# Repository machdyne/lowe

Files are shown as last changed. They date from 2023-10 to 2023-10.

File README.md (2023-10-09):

# Löwe FPGA Board

Löwe is an open-source FPGA development board for the Cologne Chip GateMate CCGM1A1.

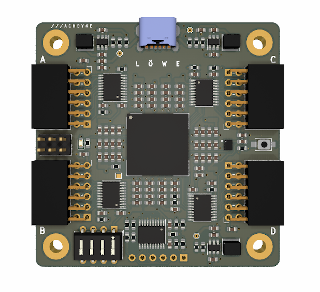
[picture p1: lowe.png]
Löwe FPGA Board


This repo contains PCB layouts, schematics, pinouts and example gateware.

Find more information on the [Löwe product page](https://machdyne.com/product/lowe-fpga-board/).

## Examples

In order to build the examples, first edit rtl/config.mk and set the paths to the location of your toolchain. You can download the toolchain from [Cologne Chip](https://colognechip.com).

You can build each example with:

```
$ make && make impl
```

You can then use [openFPGALoader](https://github.com/trabucayre/openFPGALoader) to write the gateware to SRAM or flash, using a Raspberry Pi Pico or [Werkzeug](https://github.com/machdyne/werkzeug) (loaded with [pico-dirtyJtag](https://github.com/phdussud/pico-dirtyJtag)) in this example:

```
$ openFPGALoader -c dirtyJtag count_00.cfg.bit
```

## Configuration Mode Selection

The board has 4 DIP switches that select the configuration mode:

| Switches | Mode |
| --- | --- |
| 0000 | SPI Active Mode (CPOL=0 CPHA=0) |
| 0001 | SPI Active Mode (CPOL=0 CPHA=1) |
| 0010 | SPI Active Mode (CPOL=1 CPHA=0) |
| 0011 | SPI Active Mode (CPOL=1 CPHA=1) |
| 0100 | SPI Passive Mode (CPOL=0 CPHA=0) |
| 0101 | SPI Passive Mode (CPOL=0 CPHA=1) |
| 0110 | SPI Passive Mode (CPOL=1 CPHA=0) |
| 0111 | SPI Passive Mode (CPOL=1 CPHA=1) |
| 1100 | JTAG |

## MMOD Header

See the [MMOD repo](https://github.com/machdyne/mmod/) for details.

## JTAG Header

The 3.3V JTAG header can be used to program the FPGA SRAM as well as the MMOD flash memory.

```
5 3 1
6 4 2
```

| Pin | Signal |
| --- | --- |
| 1 | TCK |
| 2 | TDI |
| 3 | TDO |
| 4 | TMS |
| 5 | 5V0[^1] |
| 6 | GND |

[^1]: This pin can be used to power the board with an external regulated 5V power supply, instead of USB power.

## Funding

This project was partially funded through the NGI0 Entrust Fund, a fund established by NLnet with financial support from the European Commission's Next Generation Internet programme.

## License

This project is released under the [CERN-OHL-P](LICENSE.txt) license.

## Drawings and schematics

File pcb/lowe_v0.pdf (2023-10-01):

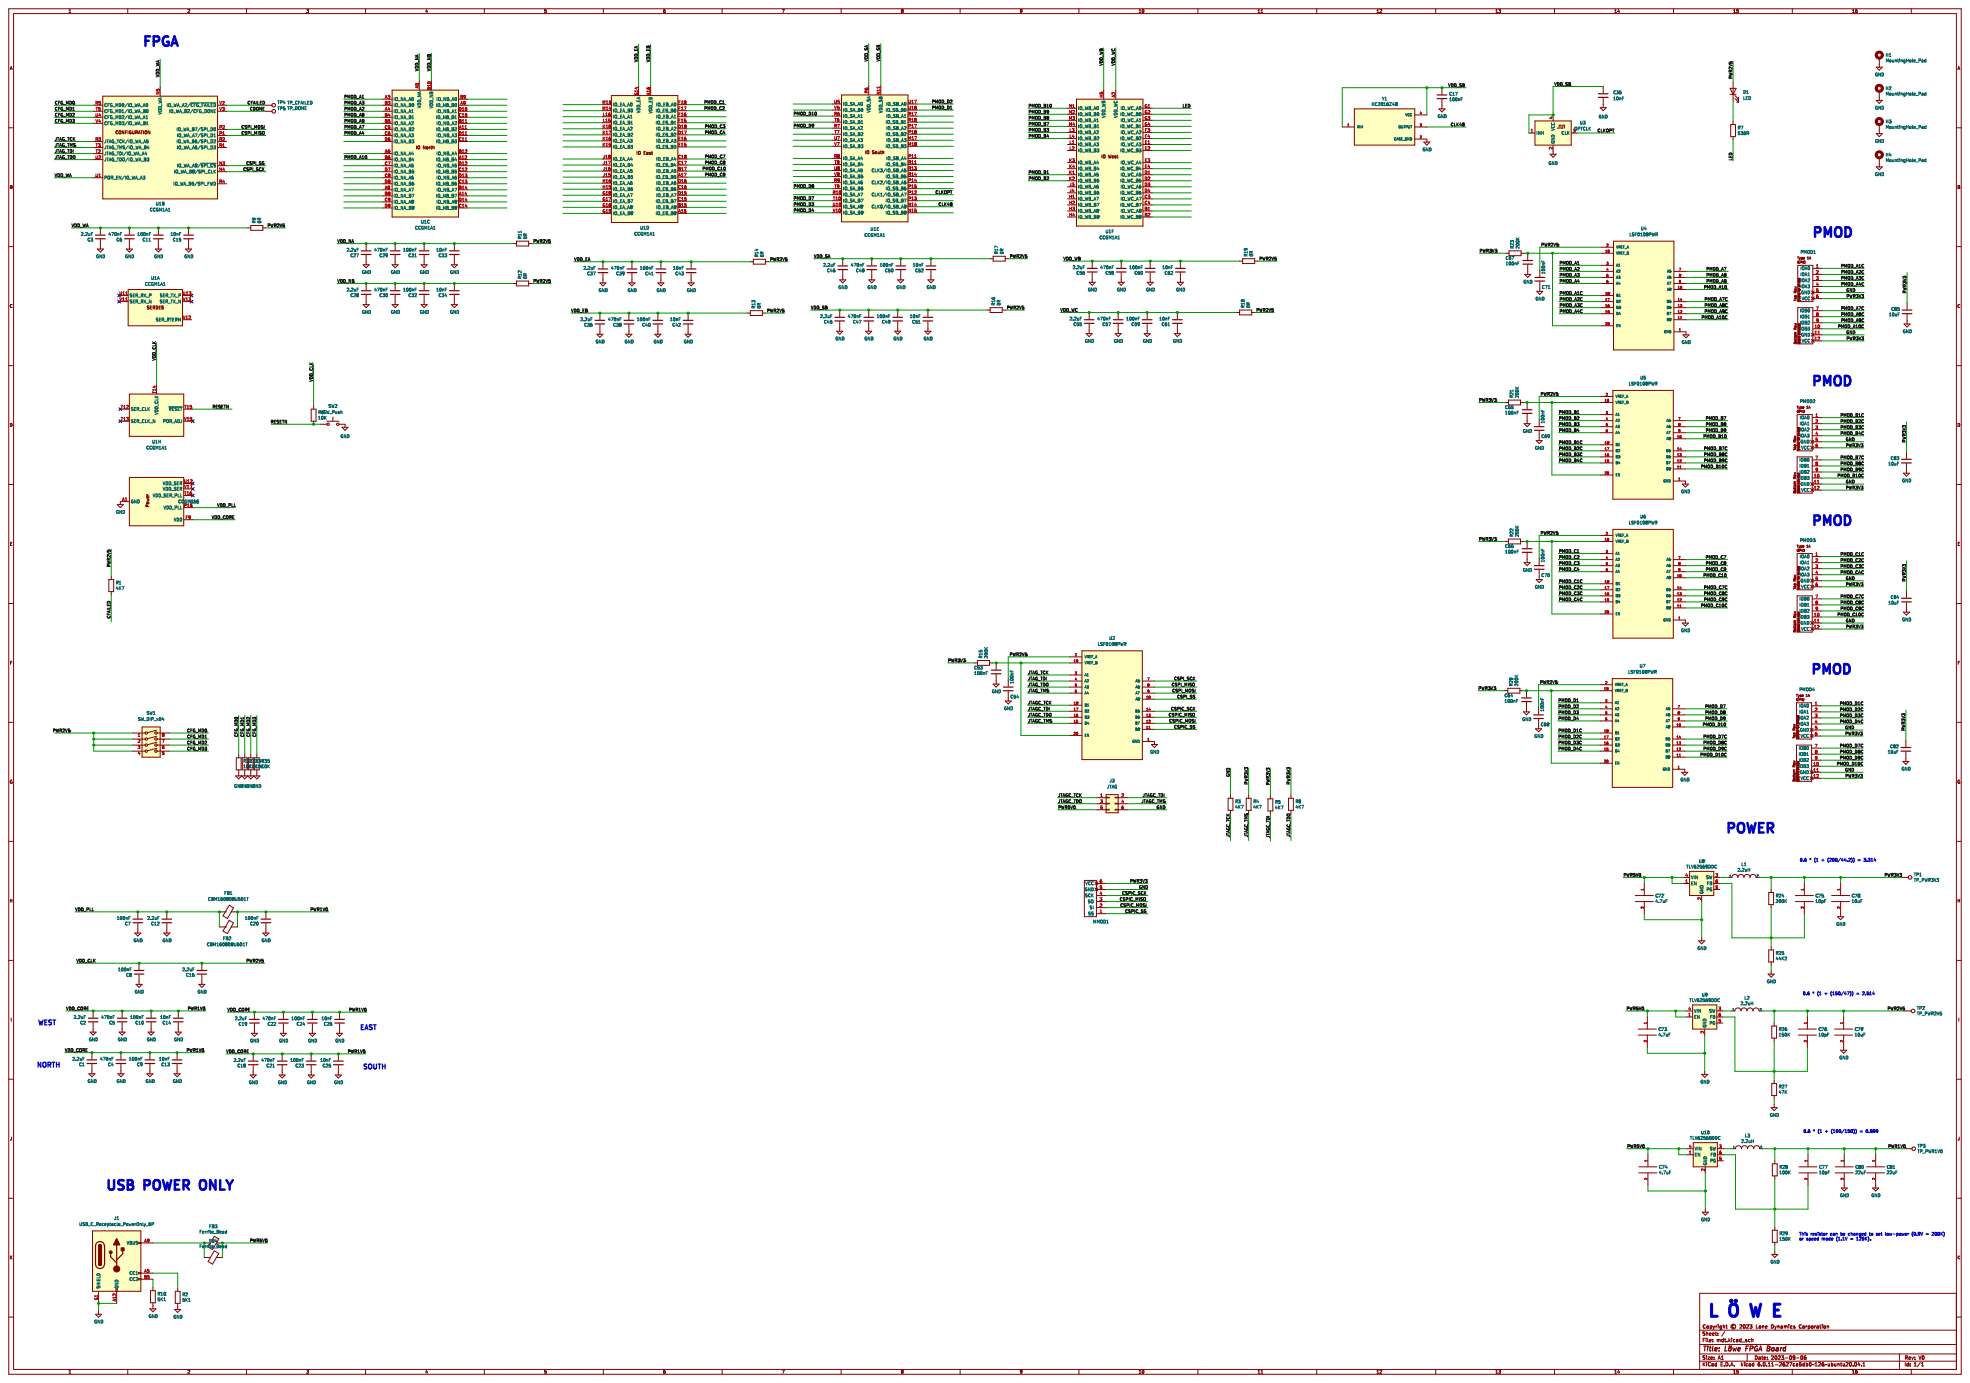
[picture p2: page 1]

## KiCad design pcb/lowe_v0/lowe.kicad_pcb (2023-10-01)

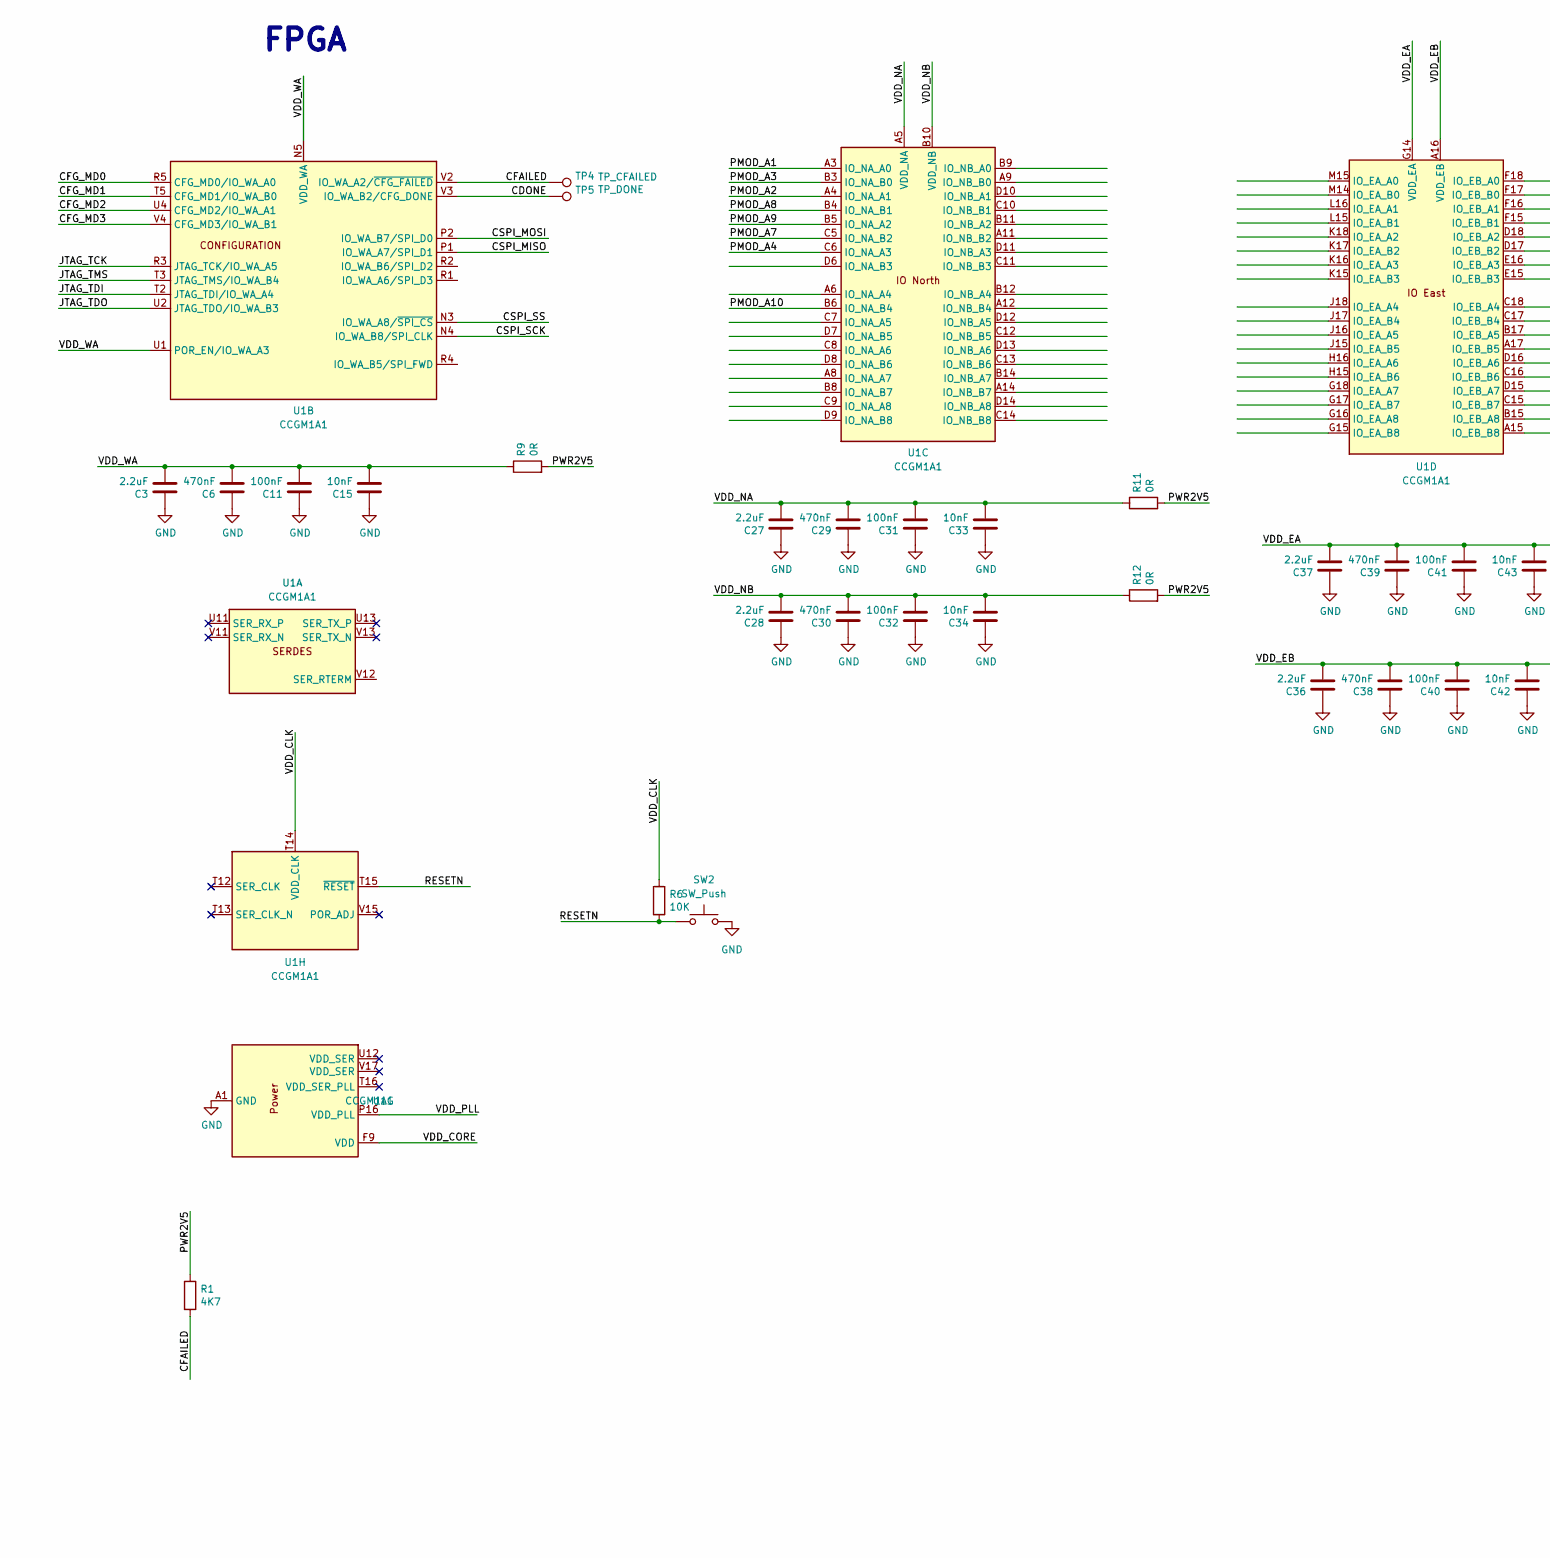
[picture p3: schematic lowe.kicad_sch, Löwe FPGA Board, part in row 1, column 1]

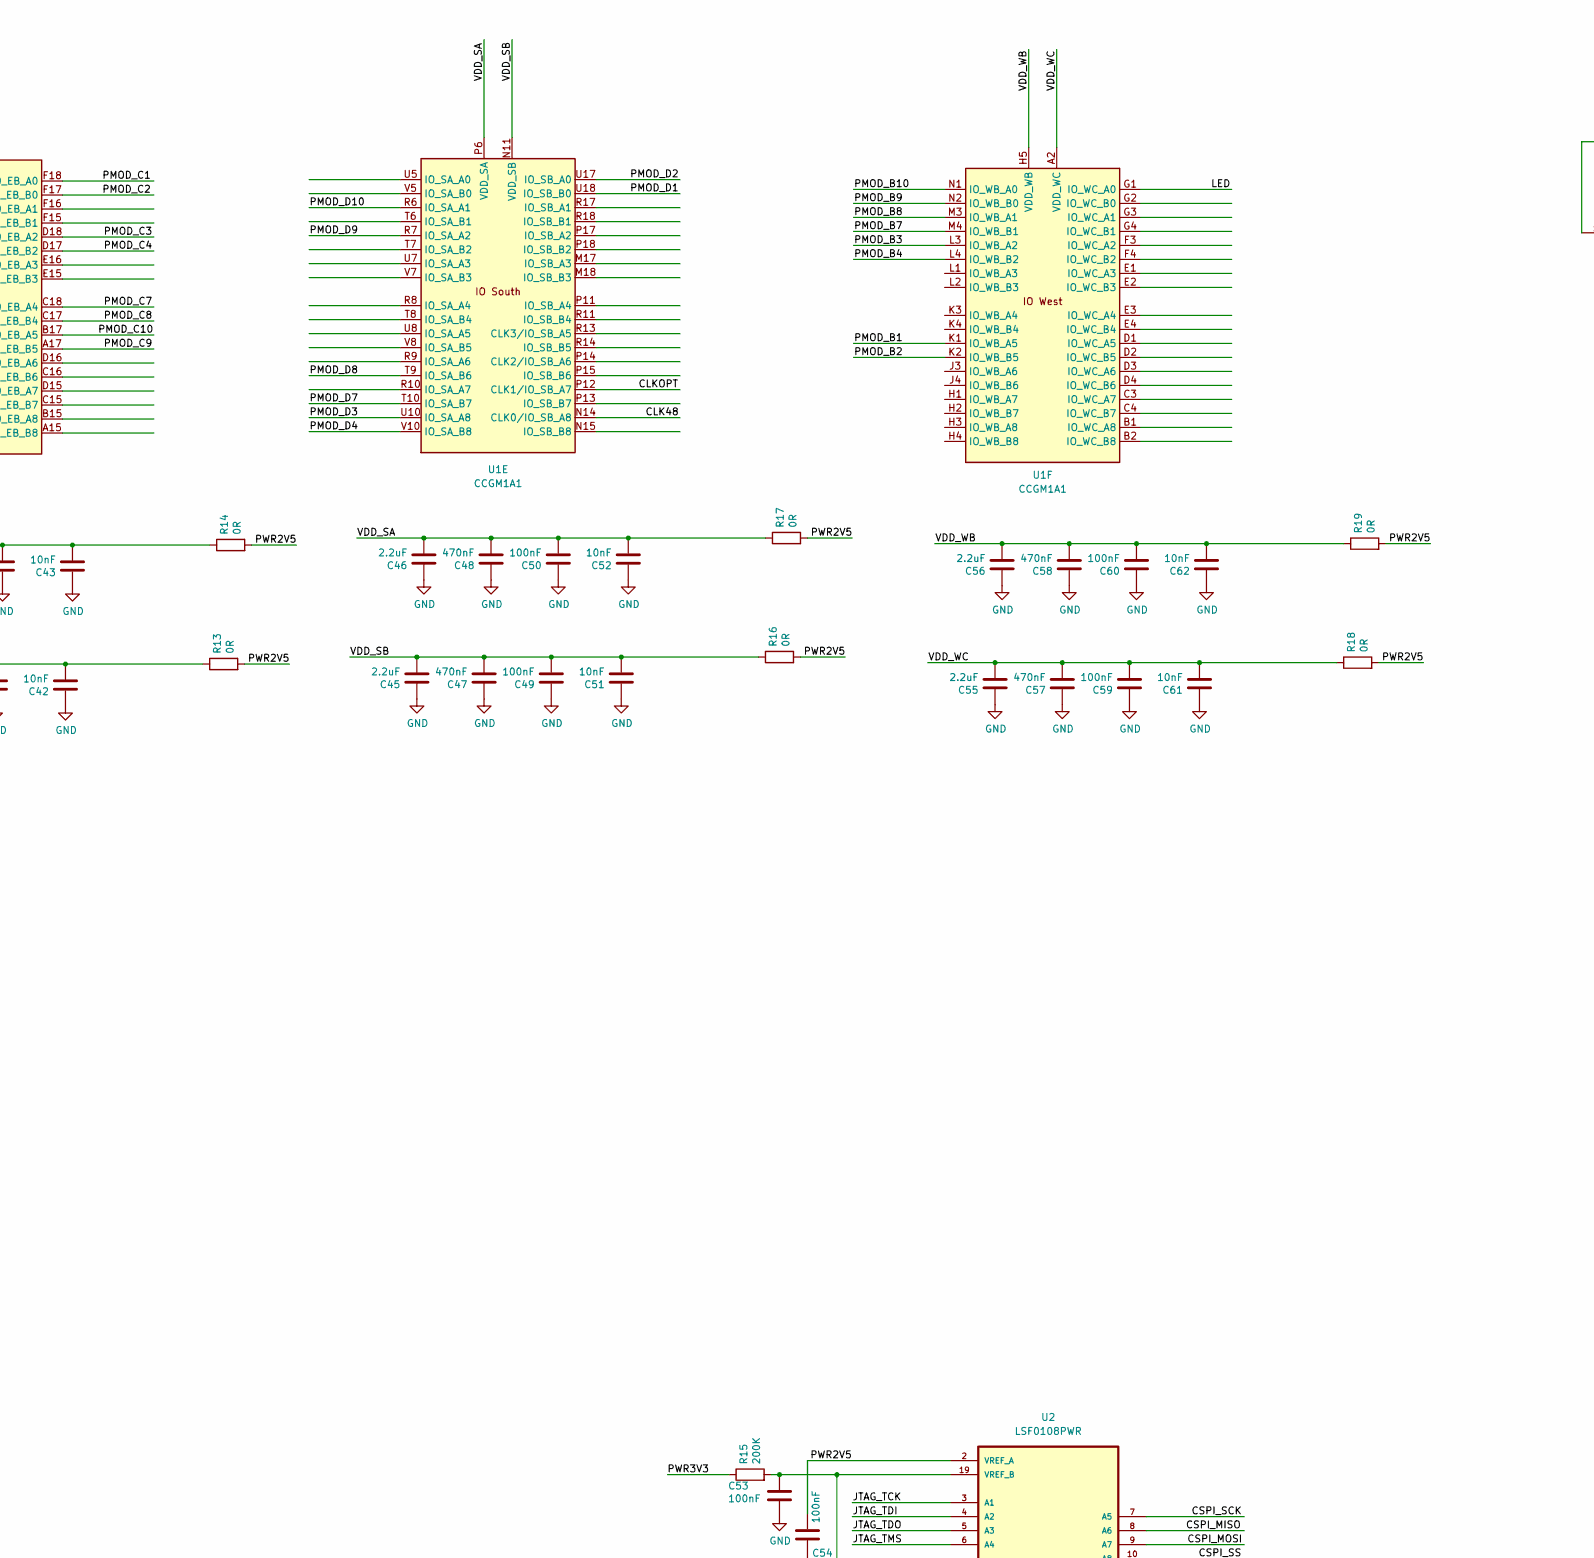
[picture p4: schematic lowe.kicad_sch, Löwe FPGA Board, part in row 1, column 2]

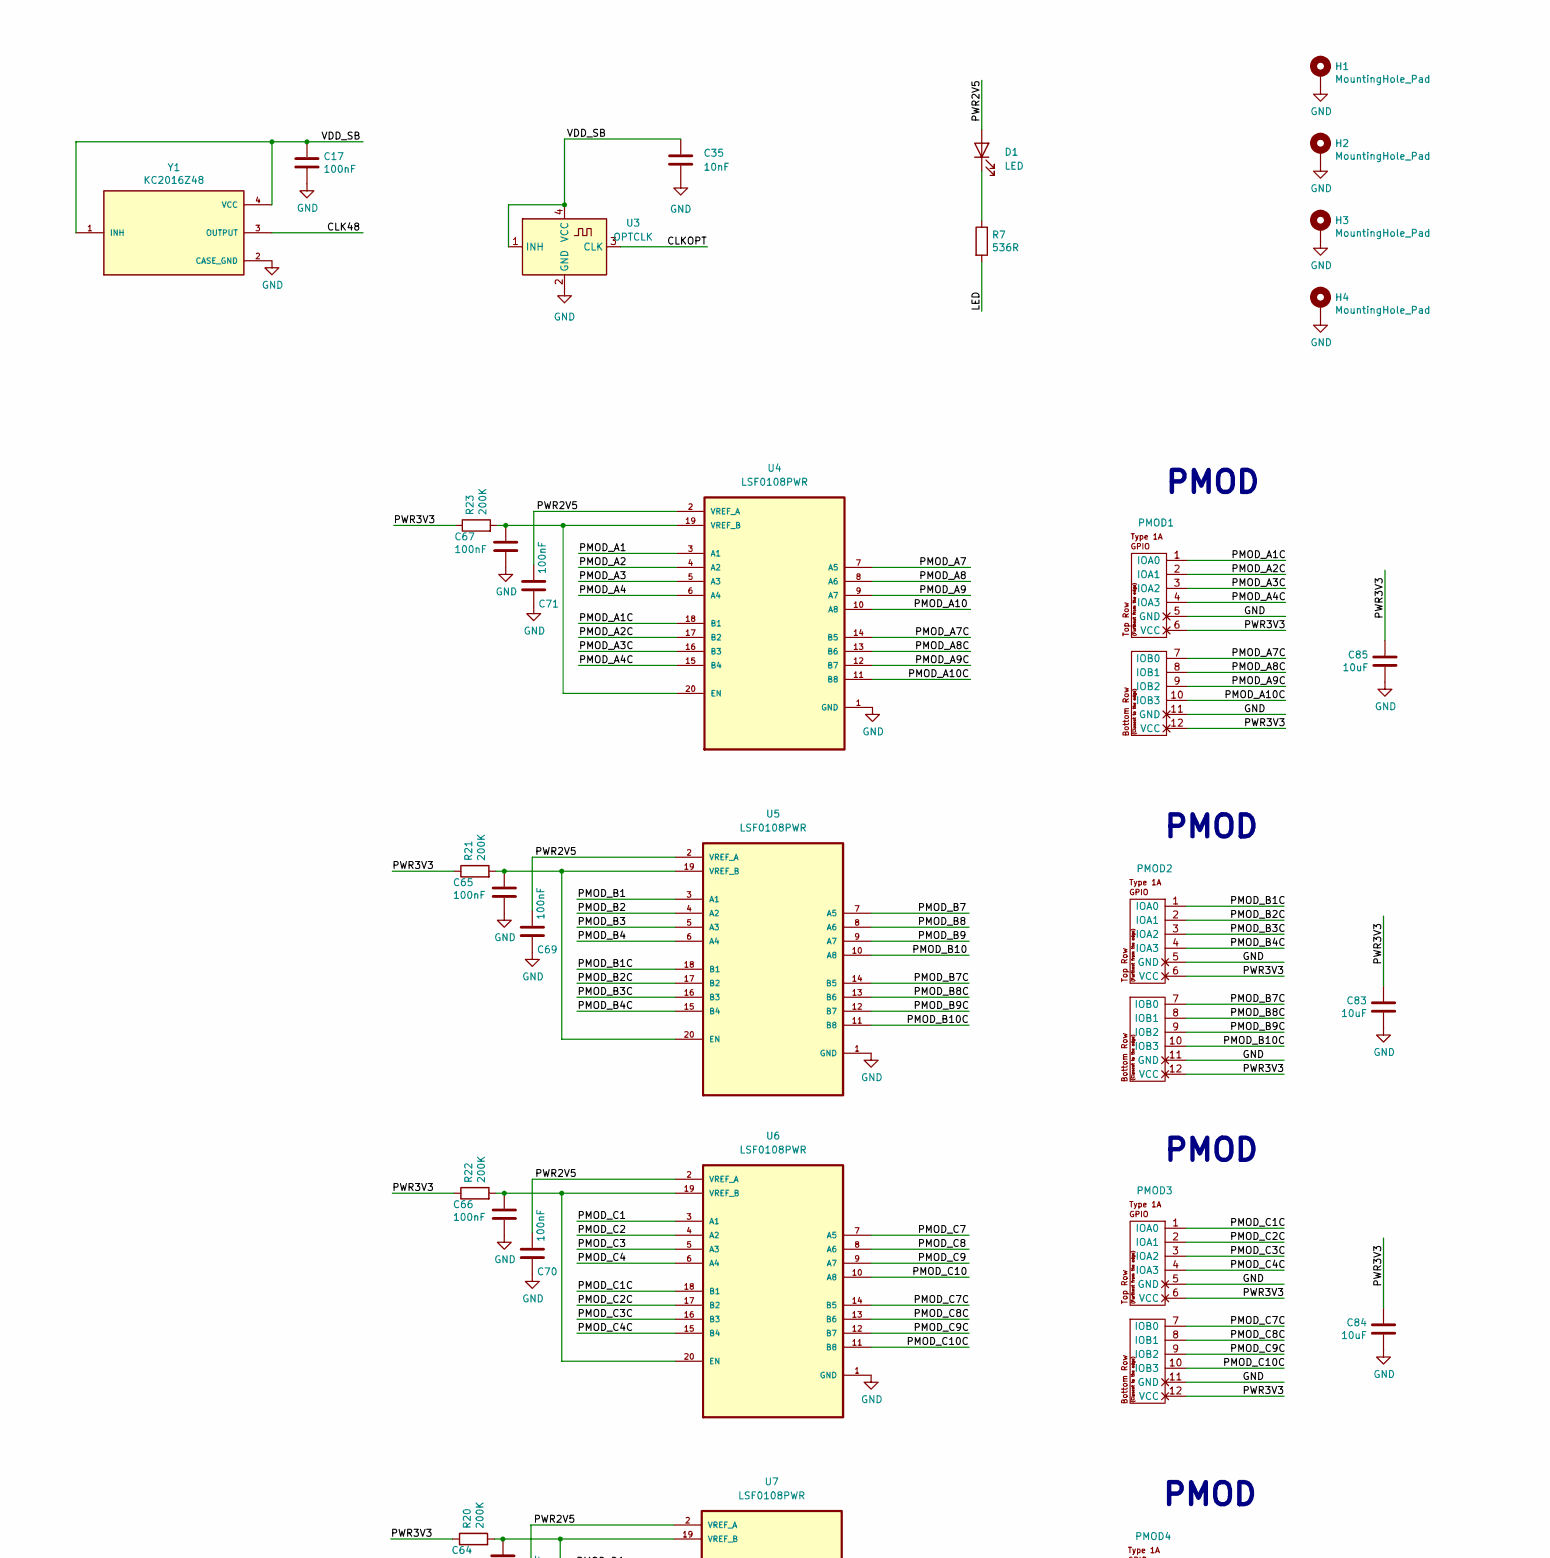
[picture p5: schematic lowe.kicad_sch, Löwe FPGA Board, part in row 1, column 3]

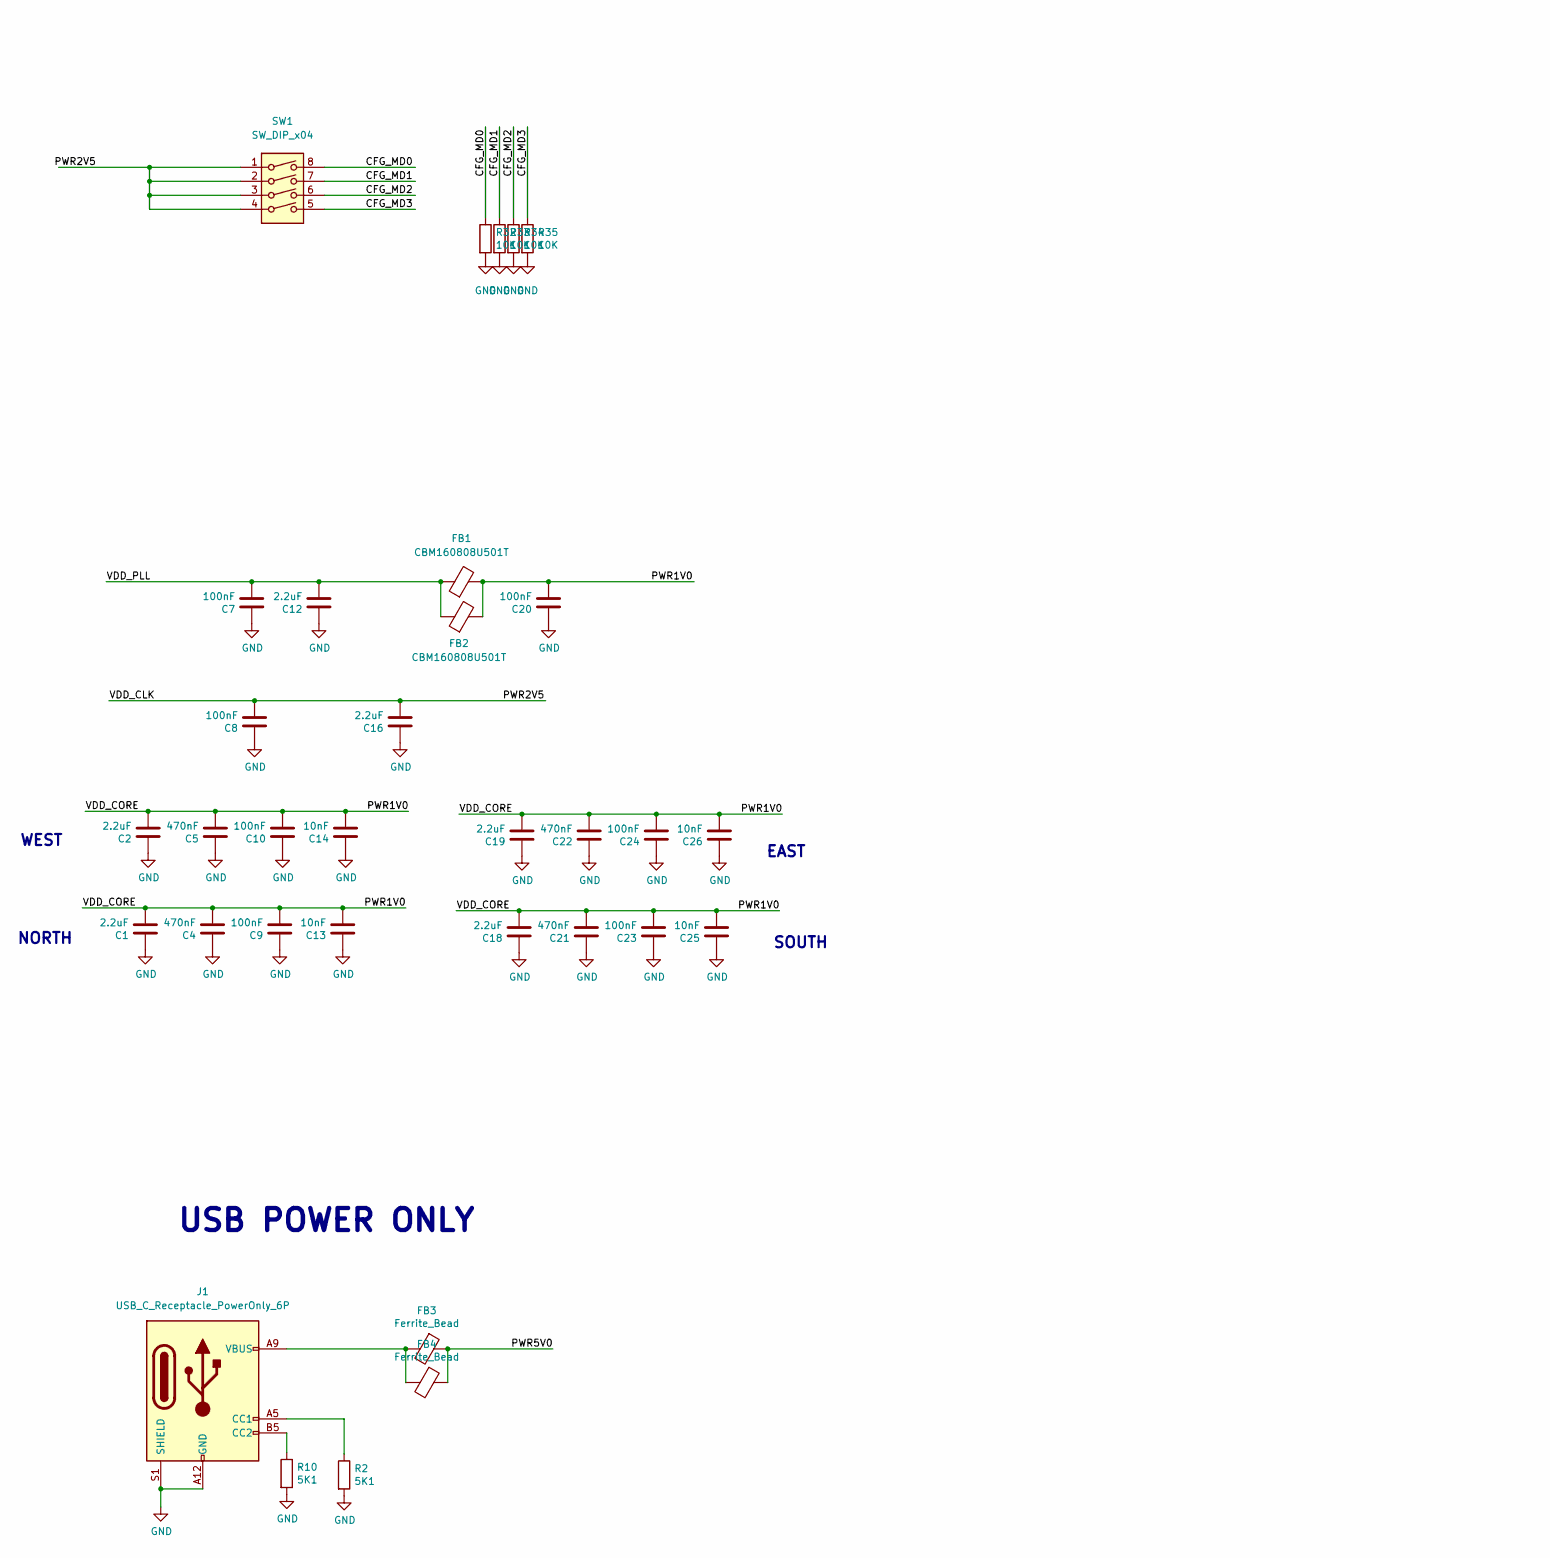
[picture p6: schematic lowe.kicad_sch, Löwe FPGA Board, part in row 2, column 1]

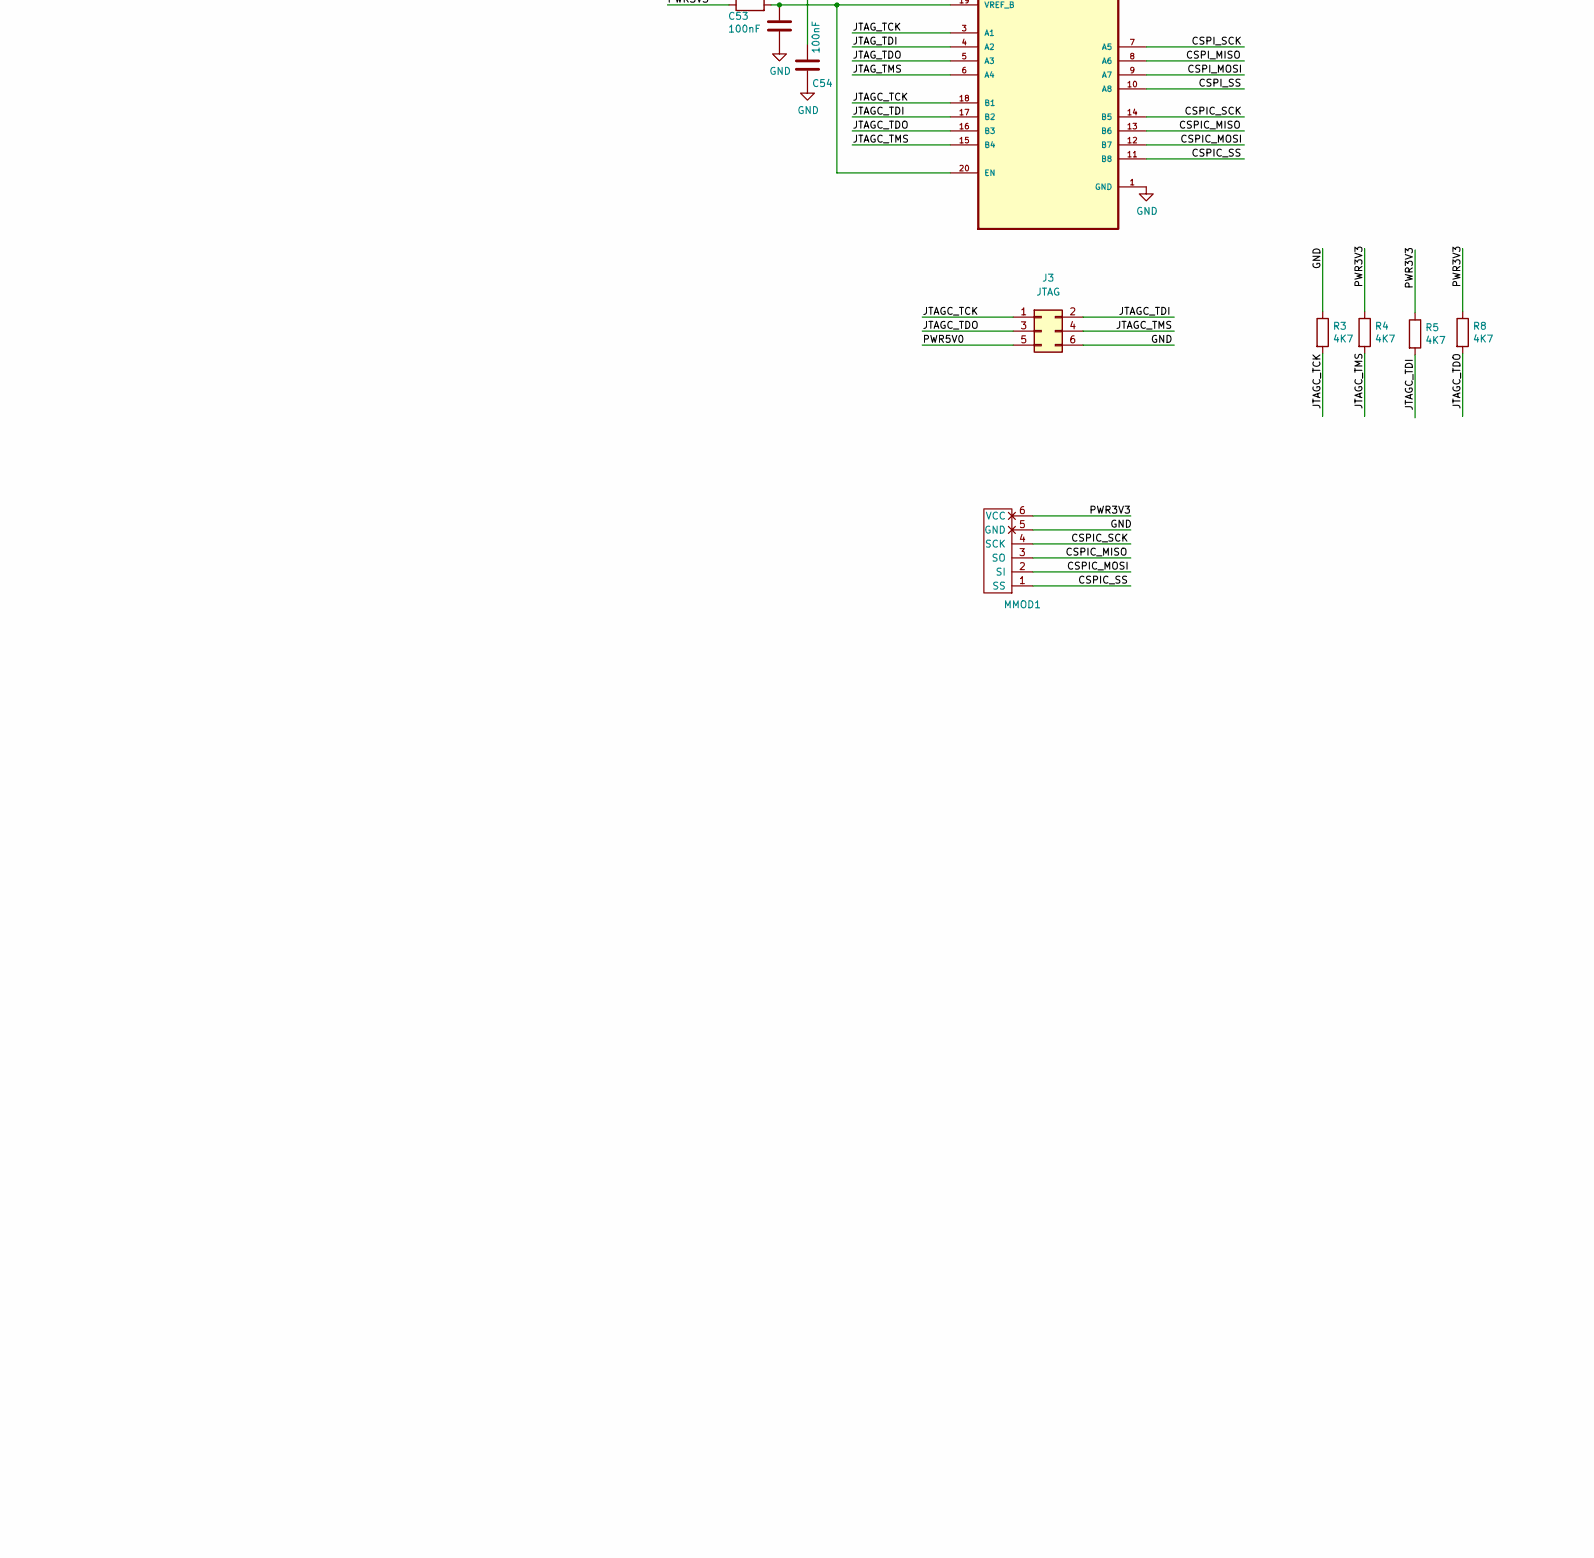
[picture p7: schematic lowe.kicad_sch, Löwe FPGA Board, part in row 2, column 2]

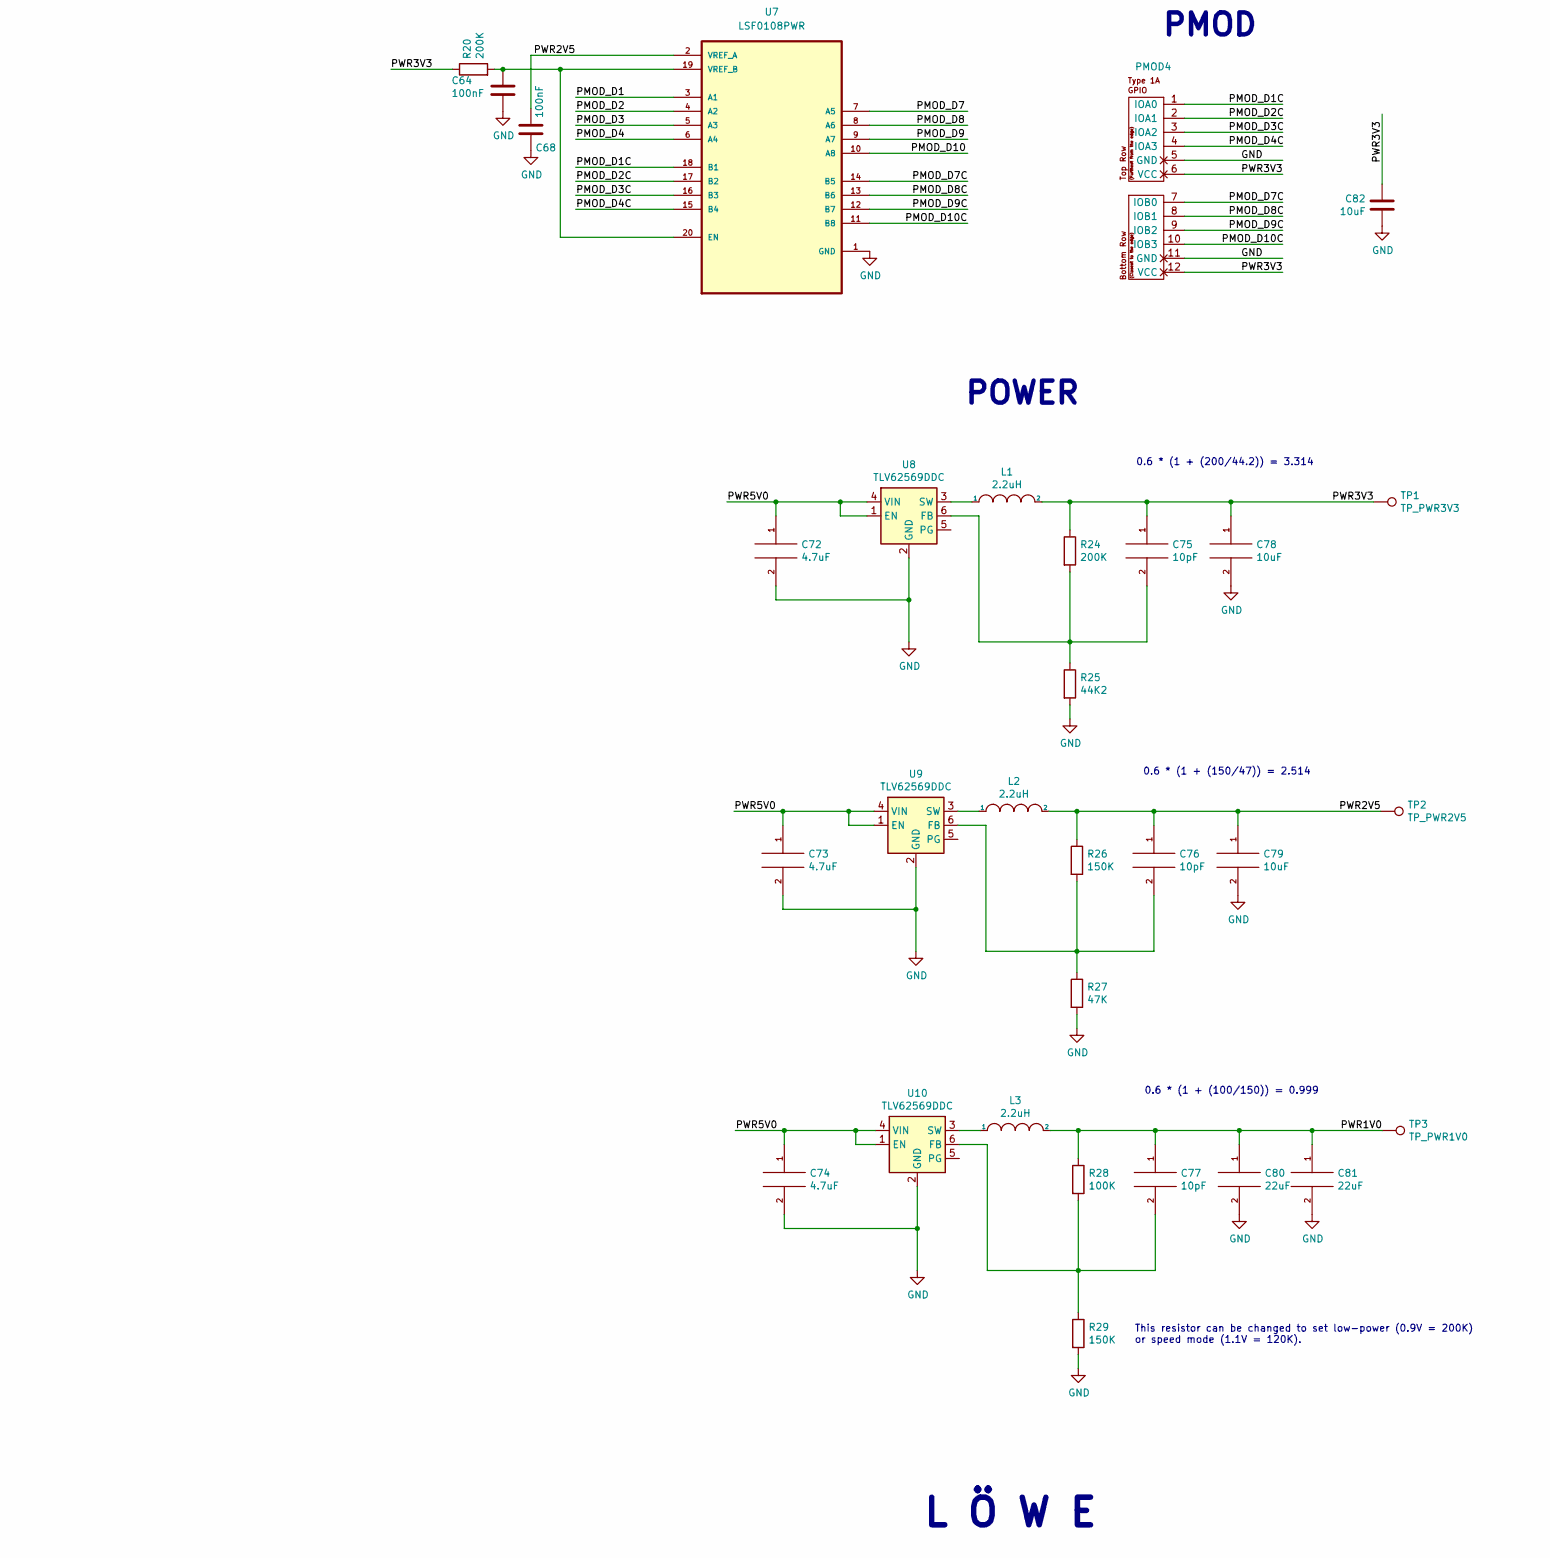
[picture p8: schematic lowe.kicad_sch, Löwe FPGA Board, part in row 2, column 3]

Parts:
C1, C2, C3, C12, C16, C18, C19, C27, C28, C36, C37, C45, C46, C55, C56: 2.2uF; C_0603_1608Metric
C4, C5, C6, C21, C22, C29, C30, C38, C39, C47, C48, C57, C58: 470nF; C_0603_1608Metric
C7, C8, C9, C10, C11, C17, C20, C23, C24, C31, C32, C40, C41, C49, C50, C53, C54, C59, C60, C64, C65, C66, C67, C68, C69, C70, C71: 100nF; C_0603_1608Metric
C13, C14, C15, C25, C26, C33, C34, C35, C42, C43, C51, C52, C61, C62: 10nF; C_0603_1608Metric
C72, C73, C74: 4.7uF; C_0603_1608Metric
C75, C76, C77: 10pF; C_0603_1608Metric
C78, C79, C82, C83, C84, C85: 10uF; C_0603_1608Metric
C80, C81: 22uF; C_0603_1608Metric
D1: LED; LED_0603_1608Metric
FB1, FB2: CBM160808U501T; R_0603_1608Metric
FB3, FB4: Ferrite_Bead; R_0603_1608Metric
H1, H2, H3, H4: MountingHole_Pad; MountingHole_3.2mm_M3_Pad
J1: USB_C_Receptacle_PowerOnly_6P; GCT_USB4125-GF-A_REVA_BIGPADS
J3: JTAG; PinHeader_2x03_P2.54mm_Vertical
L1, L2, L3: 2.2uH; L_Taiyo-Yuden_MD-4040
MMOD1: PMOD-Device-x1-Type-2-SPI; MMOD_Host_Socket
PMOD1, PMOD2, PMOD3, PMOD4: PMOD-Device-x2-Type-1A-GPIO; PMOD_2x06_HOST
R1, R3, R4, R5, R8: 4K7; R_0603_1608Metric
R2, R10: 5K1; R_0603_1608Metric
R6, R32, R33, R34, R35: 10K; R_0603_1608Metric
R7: 536R; R_0603_1608Metric
R9, R11, R12, R13, R14, R16, R17, R18, R19: 0R; LD-NETTIE-0603
R15, R20, R21, R22, R23, R24: 200K; R_0603_1608Metric
R25: 44K2; R_0603_1608Metric
R26, R29: 150K; R_0603_1608Metric
R27: 47K; R_0603_1608Metric
R28: 100K; R_0603_1608Metric
SW1: SW_DIP_x04; SW_DIP_SPSTx04_Slide_6.7x11.72mm_W7.62mm_P2.54mm_LowProfile
SW2: SW_Push; Button_2P_3x4mm
TP1: TP_PWR3V3; TestPoint_THTPad_D1.0mm_Drill0.5mm
TP2: TP_PWR2V5; TestPoint_THTPad_D1.0mm_Drill0.5mm
TP3: TP_PWR1V0; TestPoint_THTPad_D1.0mm_Drill0.5mm
TP4: TP_CFAILED; TestPoint_Pad_1.0x1.0mm
TP5: TP_DONE; TestPoint_Pad_1.0x1.0mm
U1: CCGM1A1; BGA-324_15.0x15.0mm_Layout18x18_P0.8mm_Ball0.5mm_Pad0.4mm_N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
U2, U4, U5, U6, U7: LSF0108PWR; TSSOP-20_4.4x6.5mm_P0.65mm
U3: OPTCLK; Oscillator_SMD_Kyocera_KC2520Z-4Pin_2.5x2.0mm
U8, U9, U10: TLV62569DDC; SOT-23-6
Y1: KC2016Z48; OSC_KC2016Z13.5600C1KX00; PARTREV November 2020

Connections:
/CDONE: TP5.1, U1.V3 (IO_WA_B2/CFG_DONE)
/CFAILED: R1.2, TP4.1, U1.V2 (IO_WA_A2/~CFG_FAILED)
/CFG_MD0: R32.1, SW1.8, U1.R5 (CFG_MD0/IO_WA_A0)
/CFG_MD1: R33.1, SW1.7, U1.T5 (CFG_MD1/IO_WA_B0)
/CFG_MD2: R34.1, SW1.6, U1.U4 (CFG_MD2/IO_WA_A1)
/CFG_MD3: R35.1, SW1.5, U1.V4 (CFG_MD3/IO_WA_B1)
/CLK48: U1.N14 (CLK0/IO_SB_A8), Y1.3 (OUTPUT)
/CLKOPT: U1.P12 (CLK1/IO_SB_A7), U3.3 (CLK)
/CSPIC_MISO: MMOD1.3 (SO), U2.13 (B6)
/CSPIC_MOSI: MMOD1.2 (SI), U2.12 (B7)
/CSPIC_SCK: MMOD1.4 (SCK), U2.14 (B5)
/CSPIC_SS: MMOD1.1 (SS), U2.11 (B8)
/CSPI_MISO: U1.P1 (IO_WA_A7/SPI_D1), U2.8 (A6)
/CSPI_MOSI: U1.P2 (IO_WA_B7/SPI_D0), U2.9 (A7)
/CSPI_SCK: U1.N4 (IO_WA_B8/SPI_CLK), U2.7 (A5)
/CSPI_SS: U1.N3 (IO_WA_A8/~SPI_CS), U2.10 (A8)
/JTAGC_TCK: J3.1, R3.2, U2.18 (B1)
/JTAGC_TDI: J3.2, R5.2, U2.17 (B2)
/JTAGC_TDO: J3.3, R8.2, U2.16 (B3)
/JTAGC_TMS: J3.4, R4.2, U2.15 (B4)
/JTAG_TCK: U1.R3 (JTAG_TCK/IO_WA_A5), U2.3 (A1)
/JTAG_TDI: U1.T2 (JTAG_TDI/IO_WA_A4), U2.4 (A2)
/JTAG_TDO: U1.U2 (JTAG_TDO/IO_WA_B3), U2.5 (A3)
/JTAG_TMS: U1.T3 (JTAG_TMS/IO_WA_B4), U2.6 (A4)
/LED: R7.2, U1.G1 (IO_WC_A0)
/PMOD_A1: U1.A3 (IO_NA_A0), U4.3 (A1)
/PMOD_A1C: PMOD1.1 (IOA0), U4.18 (B1)
/PMOD_A2: U1.A4 (IO_NA_A1), U4.4 (A2)
/PMOD_A2C: PMOD1.2 (IOA1), U4.17 (B2)
/PMOD_A3: U1.B3 (IO_NA_B0), U4.5 (A3)
/PMOD_A3C: PMOD1.3 (IOA2), U4.16 (B3)
/PMOD_A4: U1.C6 (IO_NA_A3), U4.6 (A4)
/PMOD_A4C: PMOD1.4 (IOA3), U4.15 (B4)
/PMOD_A7: U1.C5 (IO_NA_B2), U4.7 (A5)
/PMOD_A7C: PMOD1.7 (IOB0), U4.14 (B5)
/PMOD_A8: U1.B4 (IO_NA_B1), U4.8 (A6)
/PMOD_A8C: PMOD1.8 (IOB1), U4.13 (B6)
/PMOD_A9: U1.B5 (IO_NA_A2), U4.9 (A7)
/PMOD_A9C: PMOD1.9 (IOB2), U4.12 (B7)
/PMOD_A10: U1.B6 (IO_NA_B4), U4.10 (A8)
/PMOD_A10C: PMOD1.10 (IOB3), U4.11 (B8)
/PMOD_B1: U1.K1 (IO_WB_A5), U5.3 (A1)
/PMOD_B1C: PMOD2.1 (IOA0), U5.18 (B1)
/PMOD_B2: U1.K2 (IO_WB_B5), U5.4 (A2)
/PMOD_B2C: PMOD2.2 (IOA1), U5.17 (B2)
/PMOD_B3: U1.L3 (IO_WB_A2), U5.5 (A3)
/PMOD_B3C: PMOD2.3 (IOA2), U5.16 (B3)
/PMOD_B4: U1.L4 (IO_WB_B2), U5.6 (A4)
/PMOD_B4C: PMOD2.4 (IOA3), U5.15 (B4)
/PMOD_B7: U1.M4 (IO_WB_B1), U5.7 (A5)
/PMOD_B7C: PMOD2.7 (IOB0), U5.14 (B5)
/PMOD_B8: U1.M3 (IO_WB_A1), U5.8 (A6)
/PMOD_B8C: PMOD2.8 (IOB1), U5.13 (B6)
/PMOD_B9: U1.N2 (IO_WB_B0), U5.9 (A7)
/PMOD_B9C: PMOD2.9 (IOB2), U5.12 (B7)
/PMOD_B10: U1.N1 (IO_WB_A0), U5.10 (A8)
/PMOD_B10C: PMOD2.10 (IOB3), U5.11 (B8)
/PMOD_C1: U1.F18 (IO_EB_A0), U6.3 (A1)
/PMOD_C1C: PMOD3.1 (IOA0), U6.18 (B1)
/PMOD_C2: U1.F17 (IO_EB_B0), U6.4 (A2)
/PMOD_C2C: PMOD3.2 (IOA1), U6.17 (B2)
/PMOD_C3: U1.D18 (IO_EB_A2), U6.5 (A3)
/PMOD_C3C: PMOD3.3 (IOA2), U6.16 (B3)
/PMOD_C4: U1.D17 (IO_EB_B2), U6.6 (A4)
/PMOD_C4C: PMOD3.4 (IOA3), U6.15 (B4)
/PMOD_C7: U1.C18 (IO_EB_A4), U6.7 (A5)
/PMOD_C7C: PMOD3.7 (IOB0), U6.14 (B5)
/PMOD_C8: U1.C17 (IO_EB_B4), U6.8 (A6)
/PMOD_C8C: PMOD3.8 (IOB1), U6.13 (B6)
/PMOD_C9: U1.A17 (IO_EB_B5), U6.9 (A7)
/PMOD_C9C: PMOD3.9 (IOB2), U6.12 (B7)
/PMOD_C10: U1.B17 (IO_EB_A5), U6.10 (A8)
/PMOD_C10C: PMOD3.10 (IOB3), U6.11 (B8)
/PMOD_D1: U1.U18 (IO_SB_B0), U7.3 (A1)
/PMOD_D1C: PMOD4.1 (IOA0), U7.18 (B1)
/PMOD_D2: U1.U17 (IO_SB_A0), U7.4 (A2)
/PMOD_D2C: PMOD4.2 (IOA1), U7.17 (B2)
/PMOD_D3: U1.U10 (IO_SA_A8), U7.5 (A3)
/PMOD_D3C: PMOD4.3 (IOA2), U7.16 (B3)
/PMOD_D4: U1.V10 (IO_SA_B8), U7.6 (A4)
/PMOD_D4C: PMOD4.4 (IOA3), U7.15 (B4)
/PMOD_D7: U1.T10 (IO_SA_B7), U7.7 (A5)
/PMOD_D7C: PMOD4.7 (IOB0), U7.14 (B5)
/PMOD_D8: U1.T9 (IO_SA_B6), U7.8 (A6)
/PMOD_D8C: PMOD4.8 (IOB1), U7.13 (B6)
/PMOD_D9: U1.R7 (IO_SA_A2), U7.9 (A7)
/PMOD_D9C: PMOD4.9 (IOB2), U7.12 (B7)
/PMOD_D10: U1.R6 (IO_SA_A1), U7.10 (A8)
/PMOD_D10C: PMOD4.10 (IOB3), U7.11 (B8)
/PWR1V0: C1.2, C2.2, C4.2, C5.2, C9.2, C10.2, C13.2, C14.2, C18.2, C19.2, C20.2, C21.2, C22.2, C23.2, C24.2, C25.2, C26.2, C77.1, C80.1, C81.1, FB1.2, FB2.2, L3.2, R28.1, TP3.1, U1.F9 (VDD), U1.G6 (VDD), U1.G8 (VDD), U1.G10 (VDD), U1.G12 (VDD), U1.H7 (VDD), U1.H9 (VDD), U1.H11 (VDD), U1.H13 (VDD), U1.J6 (VDD), U1.J8 (VDD), U1.J10 (VDD), U1.J12 (VDD), U1.K7 (VDD), U1.K9 (VDD), U1.K11 (VDD), U1.K13 (VDD), U1.L6 (VDD), U1.L8 (VDD), U1.L10 (VDD), U1.L12 (VDD), U1.M7 (VDD), U1.M9 (VDD), U1.M11 (VDD), U1.M13 (VDD), U1.N6 (VDD), U1.N8 (VDD), U1.N10 (VDD)
/PWR2V5: C8.2, C16.2, C54.1, C68.1, C69.1, C70.1, C71.1, C76.1, C79.1, D1.2 (A), L2.2, R1.1, R6.1, R9.2, R11.2, R12.2, R13.2, R14.2, R16.2, R17.2, R18.2, R19.2, R26.1, SW1.1, SW1.2, SW1.3, SW1.4, TP2.1, U1.T14 (VDD_CLK), U2.2 (VREF_A), U4.2 (VREF_A), U5.2 (VREF_A), U6.2 (VREF_A), U7.2 (VREF_A)
/PWR3V3: C75.1, C78.1, C82.1, C83.1, C84.1, C85.1, L1.2, MMOD1.6 (VCC), PMOD1.6 (VCC), PMOD1.12 (VCC), PMOD2.6 (VCC), PMOD2.12 (VCC), PMOD3.6 (VCC), PMOD3.12 (VCC), PMOD4.6 (VCC), PMOD4.12 (VCC), R4.1, R5.1, R8.1, R15.1, R20.1, R21.1, R22.1, R23.1, R24.1, TP1.1
/PWR5V0: C72.1, C73.1, C74.1, FB3.1, FB4.1, J3.5, U8.1 (EN), U8.4 (VIN), U9.1 (EN), U9.4 (VIN), U10.1 (EN), U10.4 (VIN)
/RESETN: R6.2, SW2.1, U1.T15 (~RESET)
/VDD_EA: C37.2, C39.2, C41.2, C43.2, R14.1, U1.G14 (VDD_EA), U1.H17 (VDD_EA), U1.J14 (VDD_EA), U1.L14 (VDD_EA), U1.L17 (VDD_EA)
/VDD_EB: C36.2, C38.2, C40.2, C42.2, R13.1, U1.A16 (VDD_EB), U1.B18 (VDD_EB), U1.E14 (VDD_EB), U1.E17 (VDD_EB), U1.F13 (VDD_EB)
/VDD_NA: C27.2, C29.2, C31.2, C33.2, R11.1, U1.A5 (VDD_NA), U1.B7 (VDD_NA), U1.E6 (VDD_NA), U1.E8 (VDD_NA), U1.F7 (VDD_NA)
/VDD_NB: C28.2, C30.2, C32.2, C34.2, R12.1, U1.B10 (VDD_NB), U1.B13 (VDD_NB), U1.E10 (VDD_NB), U1.E12 (VDD_NB), U1.F11 (VDD_NB)
/VDD_PLL: C7.2, C12.2, FB1.1, FB2.1, U1.P16 (VDD_PLL)
/VDD_SA: C46.2, C48.2, C50.2, C52.2, R17.1, U1.P6 (VDD_SA), U1.P8 (VDD_SA), U1.P10 (VDD_SA), U1.U6 (VDD_SA), U1.U9 (VDD_SA)
/VDD_SB: C17.1, C35.1, C45.2, C47.2, C49.2, C51.2, R16.1, U1.N11 (VDD_SB), U1.N13 (VDD_SB), U1.N18 (VDD_SB), U1.R15 (VDD_SB), U1.T18 (VDD_SB), U3.1 (INH), U3.4 (VCC), Y1.1 (INH), Y1.4 (VCC)
/VDD_WA: C3.2, C6.2, C11.2, C15.2, R9.1, U1.N5 (VDD_WA), U1.P3 (VDD_WA), U1.P5 (VDD_WA), U1.T1 (VDD_WA), U1.U1 (POR_EN/IO_WA_A3), U1.U3 (VDD_WA)
/VDD_WB: C56.2, C58.2, C60.2, C62.2, R19.1, U1.H5 (VDD_WB), U1.J2 (VDD_WB), U1.K5 (VDD_WB), U1.M2 (VDD_WB), U1.M5 (VDD_WB)
/VDD_WC: C55.2, C57.2, C59.2, C61.2, R18.1, U1.A2 (VDD_WC), U1.C2 (VDD_WC), U1.D5 (VDD_WC), U1.F2 (VDD_WC), U1.F5 (VDD_WC)
GND: C1.1, C2.1, C3.1, C4.1, C5.1, C6.1, C7.1, C8.1, C9.1, C10.1, C11.1, C12.1, C13.1, C14.1, C15.1, C16.1, C17.2, C18.1, C19.1, C20.1, C21.1, C22.1, C23.1, C24.1, C25.1, C26.1, C27.1, C28.1, C29.1, C30.1, C31.1, C32.1, C33.1, C34.1, C35.2, C36.1, C37.1, C38.1, C39.1, C40.1, C41.1, C42.1, C43.1, C45.1, C46.1, C47.1, C48.1, C49.1, C50.1, C51.1, C52.1, C53.2, C54.2, C55.1, C56.1, C57.1, C58.1, C59.1, C60.1, C61.1, C62.1, C64.2, C65.2, C66.2, C67.2, C68.2, C69.2, C70.2, C71.2, C72.2, C73.2, C74.2, C78.2, C79.2, C80.2, C81.2, C82.2, C83.2, C84.2, C85.2, H1.1, H2.1, H3.1, H4.1, J1.A12 (GND), J1.B12 (GND), J1.S1 (SHIELD), J3.6, MMOD1.5 (GND), PMOD1.5 (GND), PMOD1.11 (GND), PMOD2.5 (GND), PMOD2.11 (GND), PMOD3.5 (GND), PMOD3.11 (GND), PMOD4.5 (GND), PMOD4.11 (GND), R2.2, R3.1, R10.2, R25.2, R27.2, R29.2, R32.2, R33.2, R34.2, R35.2, SW2.2, U1.A1 (GND), U1.A7 (GND), U1.A10 (GND), U1.A13 (GND), U1.A18 (GND), U1.B16 (GND), U1.C1 (GND), U1.E5 (GND), U1.E7 (GND), U1.E9 (GND), U1.E11 (GND), U1.E13 (GND), U1.E18 (GND), U1.F1 (GND), U1.F6 (GND), U1.F8 (GND), U1.F10 (GND), U1.F12 (GND), U1.F14 (GND), U1.G5 (GND), U1.G7 (GND), U1.G9 (GND), U1.G11 (GND), U1.G13 (GND), U1.H6 (GND), U1.H8 (GND), U1.H10 (GND), U1.H12 (GND), U1.H14 (GND), U1.H18 (GND), U1.J1 (GND), U1.J5 (GND), U1.J7 (GND), U1.J9 (GND), U1.J11 (GND), U1.J13 (GND), U1.K6 (GND), U1.K8 (GND), U1.K10 (GND), U1.K12 (GND), U1.K14 (GND), U1.L5 (GND), U1.L7 (GND), U1.L9 (GND), U1.L11 (GND), U1.L13 (GND), U1.L18 (GND), U1.M1 (GND), U1.M6 (GND), U1.M8 (GND), U1.M10 (GND), U1.M12 (GND), U1.M16 (GND), U1.N7 (GND), U1.N9 (GND), U1.N12 (GND), U1.N17 (GND), U1.P4 (GND), U1.P7 (GND), U1.P9 (GND), U1.R12 (GND), U1.R16 (GND), U1.T4 (GND), U1.T11 (GND), U1.T17 (GND), U1.U14 (GND), U1.U15 (GND), U1.U16 (GND), U1.V1 (GND), U1.V6 (GND), U1.V9 (GND), U1.V14 (GND), U1.V16 (GND), U1.V18 (GND), U2.1 (GND), U3.2 (GND), U4.1 (GND), U5.1 (GND), U6.1 (GND), U7.1 (GND), U8.2 (GND), U9.2 (GND), U10.2 (GND), Y1.2 (CASE_GND)
unnamed: C53.1, R15.2, U2.19 (VREF_B), U2.20 (EN)
unnamed: C64.1, R20.2, U7.19 (VREF_B), U7.20 (EN)
unnamed: C65.1, R21.2, U5.19 (VREF_B), U5.20 (EN)
unnamed: C66.1, R22.2, U6.19 (VREF_B), U6.20 (EN)
unnamed: C67.1, R23.2, U4.19 (VREF_B), U4.20 (EN)
unnamed: C75.2, R24.2, R25.1, U8.6 (FB)
unnamed: C76.2, R26.2, R27.1, U9.6 (FB)
unnamed: C77.2, R28.2, R29.1, U10.6 (FB)
unnamed: D1.1 (K), R7.1
unnamed: FB3.2, FB4.2, J1.A9 (VBUS), J1.B9 (VBUS)
unnamed: J1.A5 (CC1), R2.1
unnamed: J1.B5 (CC2), R10.1
unnamed: L1.1, U8.3 (SW)
unnamed: L2.1, U9.3 (SW)
unnamed: L3.1, U10.3 (SW)

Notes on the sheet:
EAST
This resistor can be changed to set low-power (0.9V = 200K) or speed mode (1.1V = 120K).
WEST
PMOD
FPGA
0.6 * (1 + (150/47)) = 2.514
NORTH
L Ö W E
0.6 * (1 + (100/150)) = 0.999
POWER
0.6 * (1 + (200/44.2)) = 3.314
USB POWER ONLY
SOUTH

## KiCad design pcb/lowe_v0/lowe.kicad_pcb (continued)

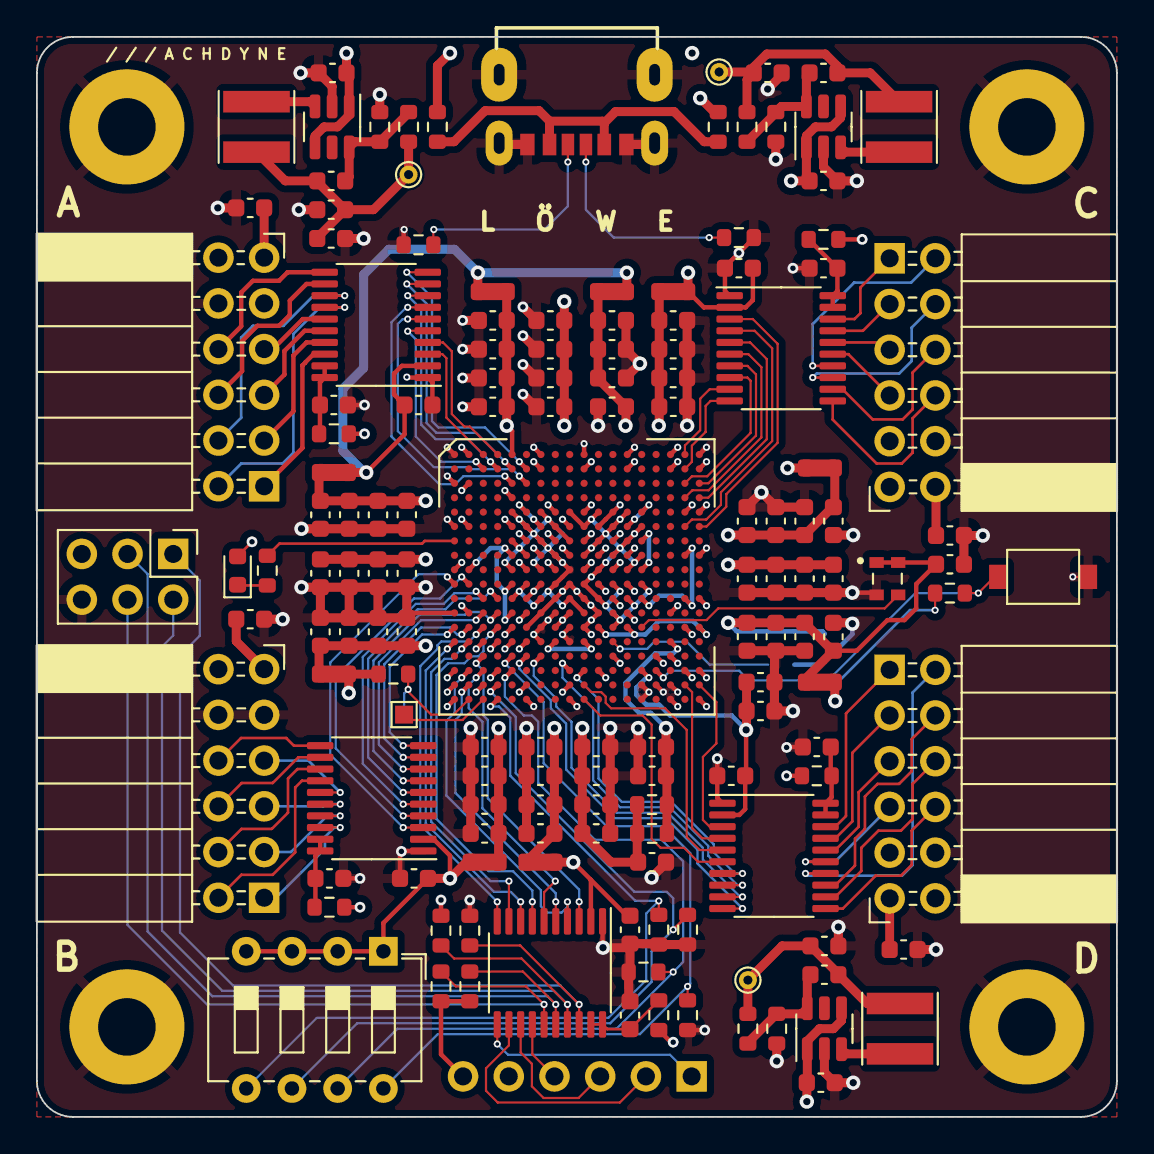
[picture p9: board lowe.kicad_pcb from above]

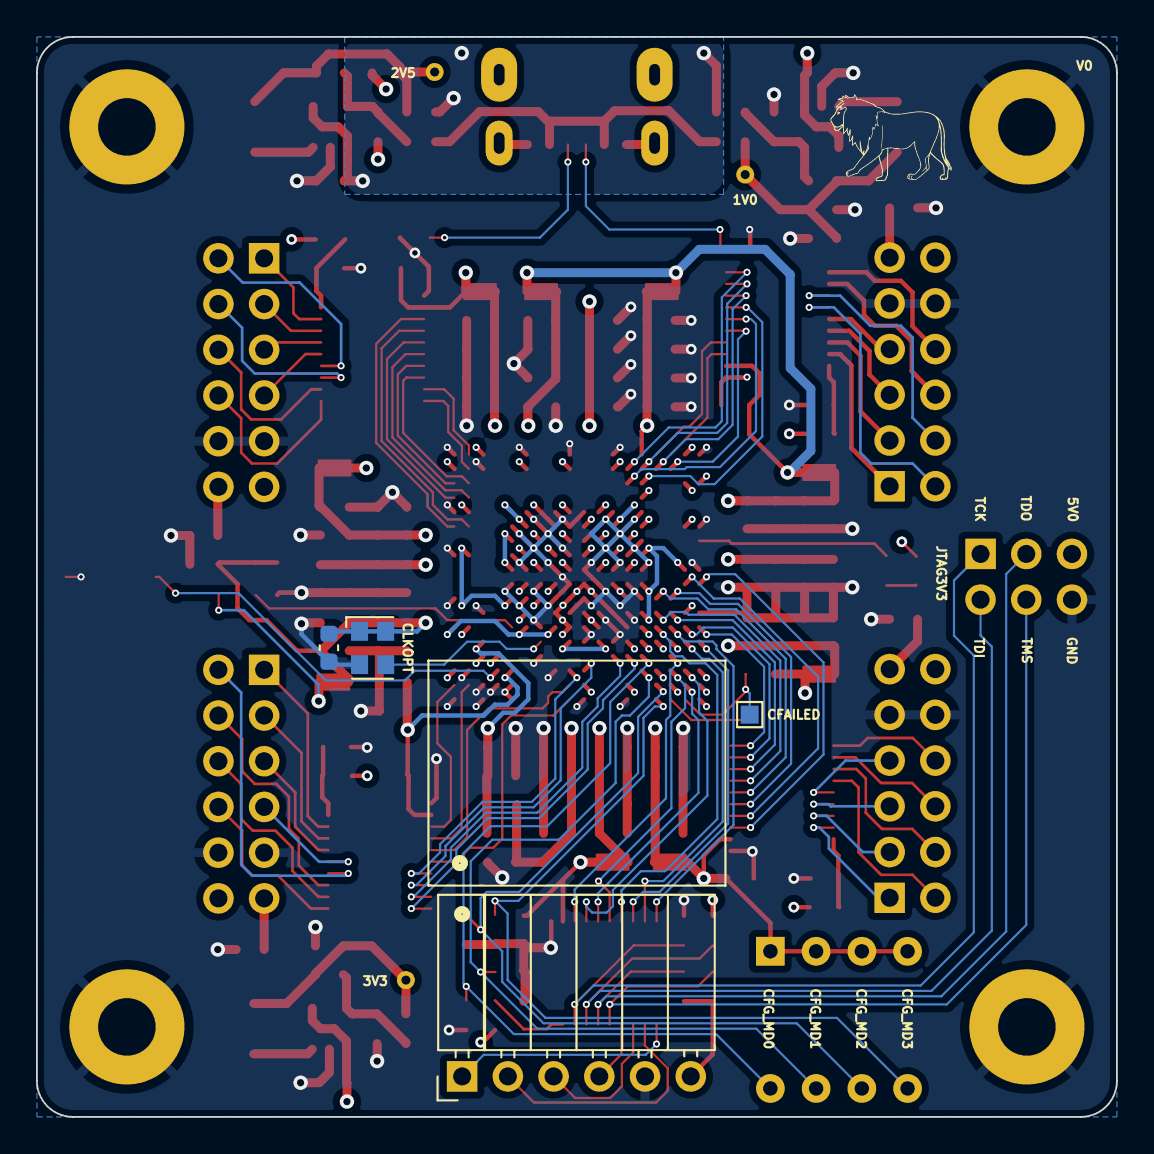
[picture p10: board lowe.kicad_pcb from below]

Board: 4 copper layers, 60.0 x 60.0 mm, 153 parts (4 on the bottom side), 120 nets.

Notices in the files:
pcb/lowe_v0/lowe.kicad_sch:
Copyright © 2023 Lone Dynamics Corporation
